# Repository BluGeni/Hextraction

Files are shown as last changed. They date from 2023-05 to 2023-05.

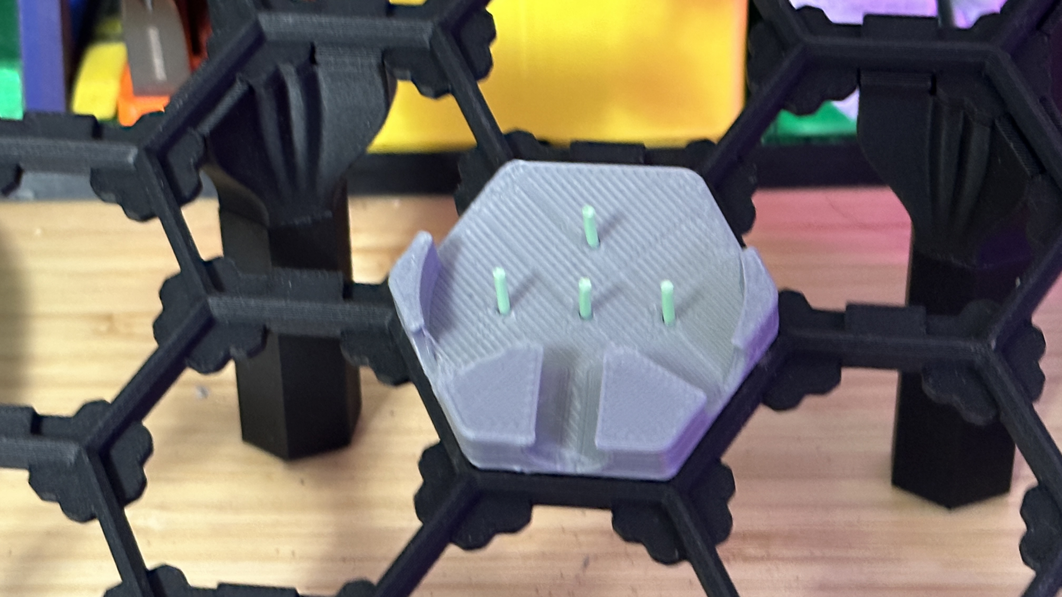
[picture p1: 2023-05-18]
STLs/Tiles/Pachinko/2023-04-21 02.33.19.jpg

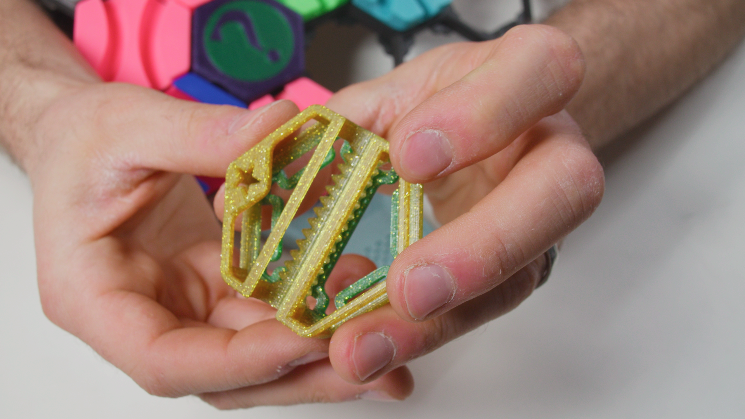
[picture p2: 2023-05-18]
STLs/Tiles/Holographic/holotile (Large).png

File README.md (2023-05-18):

I found it hard to navigate and collect all the tiles on Thangs and wanted to make it easier to see all the tiles and download them at once.

All tiles to print are in the STL folder with READMEs and links to the original are in the named folder.

Mods included:

- a full size board
- 1 piece legs - Basic

Please open a pull request or send me any files or changes you want included.

###### Discord: PapaPinkertinz#7134

# Quick Start:

### Basic Board
1 x 5-15 Plate ([If you need smaller pieces](https://thangs.com/designer/Link%20The%20Cat/3d-model/Hextraction_Board_%5Bfor%20small%20printers%5D-860793))\
1 x 5-7 Plate\
5 x Basic Clips\
2 x Basic On-Ramp\
2 x Universal End Zone\
2 x Basic Back Leg Mount\
2 x Basic Leg Segment 50mm\
2 x Basic Foot Mount Integrated\
2 x Universal Foot Integrated

### Fancy Board:
1 x 5-15 Plate ([If you need smaller pieces](https://thangs.com/designer/Link%20The%20Cat/3d-model/Hextraction_Board_%5Bfor%20small%20printers%5D-860793))\
1 x 5-7 Plate\
17 x Gutter Segment\
3 x Gutter Endcap\
2 x Gutter On-Ramp\
2 x Gutter Leg Mount\
2 x Gutter Leg Start\
2 x Gutter Foot Mount Integrated\
2 x Universal Foot Integrated\
2 x Gutter Leg Segment 50mm

### 14x Basic Tiles:

2x Asterisk Tile\
2x Peace Tile\
2x DIC Tile\
4x DC Tile\
4x X Tile

### 8x Trap Tiles:

4x Double Trap Tiles\
4x Triple Trap Tiles

### 6x Flip-Flop Tiles
These require M3 screws and washers. If these parts are unavailable, substitute 4x Pachinko Tiles and 2x King Tiles.

### 8x Secret Tiles:

2x Secret Flip Flops\
2x Secret DC\
2x Secret X\
2x Secret Lil DC\
8x Secret Lids

### 2x Teleporter Tiles:

2x In Tiles\
2x Out Tiles\
1x In Tile Card\
1x Out Tile Card

### 2x Clone Tiles:

2x Clone Tiles\
1x Clone Tile Card

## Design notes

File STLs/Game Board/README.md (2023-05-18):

These are the official game boards for Hextraction, the hackable, 3D-printable board game. I've created two versions - the Basic model uses minimal filament and prints fast. The "Fancy" Gutter version has many useful features, like ball-catching gutters and detachable feet, but consumes considerably more filament and time.

Basic Board
1 x 5-15 Plate
1 x 5-7 Plate
5 x Basic Clips
2 x Basic On-Ramp
2 x Universal End Zone
2 x Basic Back Leg Mount
2 x Basic Leg Segment 50mm
2 x Basic Foot Mount Integrated
2 x Universal Foot Integrated

Fancy Board:
1 x 5-15 Plate
1 x 5-7 Plate
17 x Gutter Segment
3 x Gutter Endcap
2 x Gutter On-Ramp
2 x Gutter Leg Mount
2 x Gutter Leg Start
2 x Gutter Foot Mount Integrated
2 x Universal Foot Integrated
2 x Gutter Leg Segment 50mm

For assembly instructions for a basic board, watch the Hextraction launch video!

I've designed this to be as modular as possible, so you can create boards of any shape and size. If you're sizing a leg for a given slot, you want it to be 25mm taller for every additional slot between it and the end zone.

Fusion 360 source: https://a360.co/3H6op2f

Hextraction is a 3D-printable, modder-friendly board game designed by me, Zack Freedman of Voidstar Lab. In addition to tiles, you'll also need 10mm steel balls or 3/8" slingshot ammo and a game board. To learn the rules and how to get started, watch the Hextraction video!

Hextraction is absolutely free - it's free of charge - all of my models are here on Thangs, commercial use allowed. It's free-form - you can play with any number of opponents, even zero. It's free to modify - you can create your own tiles and configure your own board.

For more information, visit https://playhextraction.com.

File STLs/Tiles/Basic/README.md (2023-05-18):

These tiles might be nothing but tracks, but they're the bread and butter of the entire game. Along with the board, these are the foundation of Hextraction, the hackable, 3D-printable board game.

These basic tiles are the core of the game - they build more momentum than fancy mechanisms, and they make the game move faster than complex effects. I recommend putting at least one basic tile into the pool per non-basic tile.

The tiles are named for the tracks' appearance - they're not abbreviations, so don't read too far into them!

I also included a blank tile - PLEASE don't print this! It's a base for your own designs, if you'd prefer not to start in Fusion 360.

Fusion 360 source: https://a360.co/42u6wDc
The S and Z tiles were a late addition, so they have a separate source file: https://a360.co/3VYpz6d

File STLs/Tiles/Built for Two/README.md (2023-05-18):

Stretch your turn to the limit with this eye-popping mechanical tile that unfolds to hustle your ball to the end zone. Make foes flip their lids with this wacky tile for Hextraction, the hackable, 3D-printable board game.

The Tile Built for Two is probably the wildest tile I've ever made - it unfolds like a locket to occupy two slots. Or not - the tile still works when it's folded, so you can drop the whole shebang if you're not interested in living large.

Just remember the rules; you have to play the tile and THEN unfold it, so if the adjacent spot is occupied, you can't whip it out. You can only manipulate mechanisms as you play the tile, and immediately afterward, so if that slot opens up, you're stuck. Still, if you have a way to return this to your hand, maybe you can do some surprise plays?

To keep the profile slim, this tile has lower walls than average. Be careful entering at an angle - you might go right over the top.

Print one top, one bottom, and two links. Use M2x8 screws to connect it up. It'll be a very loose fit - this is important to make it fit all kinds of boards. I recommend gluing a few 6x2mm magnets in the holes to hold it shut.

Fusion 360 source: https://a360.co/3psg0Ab

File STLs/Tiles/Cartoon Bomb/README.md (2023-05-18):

Turn your opponents' plans into a smoldering crater with this bulbous banger. It might be the most excessive explosive in Hextraction, the hackable, 3D-printable board game.

The Enormous Cartoon Bomb is pretty much what it says on the tin - it's a big, fat cannonball bomb ripped straight out of Looney Tunes and plopped right onto your game board. The effect triggers when the three-ball rule destroys the tile, causing it to take all of its neighbors down with it. For best results, line up a few copies in a combustible conga line to set up a devastating chain reaction.

This tile isn't just silly - it's genuinely useful in multiplayer games, where conflicting plays constantly clog up the board. It'll create just enough breathing room to get a new tile in play, while significantly delaying the Overdrive endgame. Don't forget that rules card!

Fusion 360 source: https://a360.co/41xxU1R

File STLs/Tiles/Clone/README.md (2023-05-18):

Any fan of pro cycling or late-30's European history will tell you: Two balls are better than one. Double your fun with this special tile for Hextraction, the hackable, 3D printable board game.

When a ball passes through the jagged trigger area, roll another ball down the ramp. It's simple but surprisingly powerful, and part of my recommended "starter kit."

Print one or more tiles and snap off the built-in supports, and don't forget to print the rules card!

Fusion 360 source: https://a360.co/44Vb5Im

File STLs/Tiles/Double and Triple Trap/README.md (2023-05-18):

Craft sneaky strategies with these tricky tiles! They trap the first ball to enter each path, allowing you to outmaneuver foes in Hextraction, the hackable, 3D-printable board game.

The Triple Trap Tile can trap up to two balls, one each in different directions. Be careful entering too fast... it can be a bit touchy.

The Double Trap Tile only captures a single ball, but can be installed in four different orientations. It will occasionally trap too many balls, which are easy to knock loose!

Double Trap source: https://a360.co/3H2dJBS
Triple Trap source: https://a360.co/3MoaVC5

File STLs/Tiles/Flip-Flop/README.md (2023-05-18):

This simple mechanism alternates between sending balls left and right. It's one of the most important tiles in Hextraction, the hackable, 3D-printable board game.

Print one Tile and one Flipper, ideally in PETG or nylon. Insert an M3x8 or M3x10 screw in the flipper, drop an M3 washer onto the tile, align the peg on the flipper with the slot on the tile, and screw it down. Make sure the flipper spins loosely and freely - it might need a touch of grease.

I also snuck in an Advanced version with more entrances. It's more versatile, but also more complex. I recommend printing the basic version first, then upgrading to the Advanced version later.

Fusion 360 source: https://a360.co/3o6D86W

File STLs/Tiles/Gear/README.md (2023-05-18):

Make your foes' heads spin with this revolutionary tile for Hextraction, the hackable, 3D-printable board game.

The Gear Tile's triggered effect lets you lift up an adjacent tile and turn it one notch in either direction. Remember, a notch isn't 60 degrees, it's as far as necessary to make it sit flat. Just be careful if it's got balls on it; if they fall off the tile, you're the one who rolled them! Pull off ten-dimensional gigabrain plays like toggling paths, reversing mechanisms, resetting Trap Tiles, flipping Launchers, and more.

The tile itself can also create some neat strategies - that big peg in the middle can make it behave like a Pachinko, Peace, or DIC Tile.

Don't forget to print that rules card... and some on-theme steampunk copper filament.

Fusion 360 source: https://a360.co/3I9UIxI

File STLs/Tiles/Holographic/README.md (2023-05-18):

Overload the game board in record time with the Holographic Tileframe, a crazy-looking effect tile for Hextraction, the hackable, 3D-printable board game!

It looks like a wireframe, but acts like a time machine - after your ball passes through its skeletonized body, you can play another tile where the path cuts out. Not only does it turbocharge the race to the bottom, it lets you waste opponents' turns by redirecting them off the edge, while giving you twice as many new tiles to throw at them! Don't play this tile recklessly - unless you have a clever trick to jam up your opponent, you might help them more than yourself!

Print the Holo Bottom, the Holo Card, and two each Left Top and Right Top. Glue one set of Tops to the tile, and the other to the rules card.

The crazy aesthetics come at a cost - the Tileframe is the lightest and most fragile tile. Use a tough filament like ABS, and look out for Launchers and straightaways; a high-speed ball can blow it right off the board!

Fusion 360 source: https://a360.co/42NduCU

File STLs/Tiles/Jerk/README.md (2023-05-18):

Sorry, oops, coming through, don't mind me... nothing's more annoying than an overly polite tile shouldering in on your turf. Shove your way to victory - gently - with this tactically awkward utility tile for Hextraction, the hackable, 3D printable board game.

As a rare self-explaining tile, this one has the rule printed right in - when you play it, swap it with an adjacent tile. It also tells you to apologize, though Rule 0 keeps this from affecting the gameplay. Do it if you want, or don't... you jerk.

Not only does it have nothing but a single teeny-tiny turn, it can be placed in "illegal" ball-trapping positions. Y'know, in case shoving your opponents' plans aside isn't obnoxious enough already.

Also, you can technically use this to move a ball up the board if you play it next to some kind of King Tile variant that lets you wait a turn? I don't know, this tile's a jerk.

Fusion 360 source: https://a360.co/3o1hnFS

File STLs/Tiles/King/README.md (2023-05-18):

This tile travels across the game with a ball on board, opening big-brain plays almost as bizarre as en passant. Put your foes in check with this chess-inspired tile for Hextraction, the hackable, 3D-printable board game.

Even though it's got a neat self-resetting mechanism, this tile is fully printed, so if you don't have the hardware to make the Flipper Tile, you can capture some of its gameplay with the King. Since it needs open slots to work, it's strongest in the early and midgame. Consider adding some Bomb Tiles and other tile removers to open up more wiggle room!

I strongly recommend printing the Spring in PLA for stiffness, and the other components in PETG or nylon for smoothness. Print the Knob with the icon facing up, and the Upper with arrows against the plate, supports enabled. The Lower, Spring, and Kard don't need supports. To assemble:

Put a thin bead of glue around the center peg on the King Lower, drop in the Spring flat side down, and let it set.
If possible, apply some plastic-safe grease to the Knob's underside and tabs.
Push the Knob into the Upper, and make sure the Knob's tabs nest into the Upper's tracks.
Apply glue to the four pegs on the Lower. Drop the Knob and Upper onto the Lower and let the glue set.
If necessary, apply more grease to make the motion smooth.
Fusion 360 source: https://a360.co/45aGjeT

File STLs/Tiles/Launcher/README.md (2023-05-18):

Make a strategy that defies gravity with this kinetic tile for Hextraction, the hackable, 3D-printable board game. Warning: It'll put your eye out.

When a ball enters the Launcher Tile, its effect activates - pull back the spring-loaded pusher and release it to fire the ball into the upper-left or upper-right edge. Positioning is important - since almost every tile is designed for balls to enter the TOP edges, very few will work if you start at the wrong end of the ice-cream cone. Prepare by stocking the pool with extra Asterisks, Pachinkos, Gears, "illegal" basics, and other compatible tiles. The Flipper Tile actually DOES work with the Launcher, provided the flipper is pointing in the other direction.

For the strongest launch, brace the tile against the board with one hand, while using the other to launch. The snappier the release, the stronger the launch. PLEASE don't let kids play with this tile - while it shouldn't be powerful enough to injure anyone, accidents do happen. You also don't want your vile offspring firing pencils out of this thing.

The Launcher Tile has a print-in-place mechanism - simply print the tile with supports enabled on the build plate only. Don't use PLA or composites - you need the lowest friction possible. After printing and cleaning up, use a Q-tip or toothpick to apply a plastic-safe grease to the slider track, and use tweezers to install a McMaster 9044K11 extension spring on the pegs below. Depending on your printer's support interface settings, you may need to thin the pegs down with a craft knife to fit the spring.

Also, don't forget to print the rules card - this uses a triggered effect to fire the ball!

Fusion 360 source: https://a360.co/3LWqEXA

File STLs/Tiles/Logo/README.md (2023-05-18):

I designed these tiles for the release video of Hextraction, the hackable, 3D-printable board game. They're meant to be decorative, but if you're adventurous, you could play them! My goal was a cool-looking title card shot and thumbnail, not fun gameplay, so they have downright bizarre track arrangements that don't work in many orientations. If you're an experienced player, these could spice up your pool without bogging you down with rules and mechanisms. If you're new, I recommend printing another tile instead.

Print the A parts face-down on the plate, and the B parts face-up. Enable ironing on all top surfaces. Print the Overlays in a contrasting color. Glue each tile's A and B parts together, then glue the Overlay on top.

While these have notches in all six positions, they were intended to be installed with the text pointing towards the bottom-right. Other orientations will make many of the paths unusable. Also, be gentle - these tiles weren't intended to be shuffled, so they're particularly fragile.

If you'd like to improve these, I recommend closing some of the notches to restrict the orientations, and maybe rearranging some of the tracks. I was also thinking of adding a rule: "The 'TRAC' tile overwrites the 'HEX' tile's neighbors, and the 'TION' tile overwrites the 'TRAC' tile's neighbors." Or maybe "When a roll ends, if the 'HEX,' 'TRAC,' and 'TION' tiles were touched exactly once, in that order, rearrange any number of tiles and roll again."

Fusion 360 source: https://a360.co/42ywXYu

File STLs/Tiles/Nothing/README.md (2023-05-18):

When nothing remains, everything is equally possible. Dump your hand with this simple utility tile for Hextraction, the hackable, 3D printable board game.

I developed this as an example of a self-explaining tile - you don't need a rules card if the rule is on the tile itself! Discarding your hand is a big deal in Magic, but in Hextraction, it just means you get to cycle in a new one at the end of your turn. The tile's bare-bones path means you'll always have a place to play it. Between us nerds, this one also lets you set up some "illegal" plays that connect the top edge to a top-side edge. Make sure the ball has some momentum!

Fusion 360 source: https://a360.co/42NcFKk

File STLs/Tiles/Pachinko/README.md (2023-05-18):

Let chaos reign with this unpredictable tile! Who knows where the ball will end up?

After printing, wedge some small pieces of filament into the holes to make the pegs. If the holes come out too small, touch up with a 2mm drill. You can also use M2 screws.

Fusion 360 source: https://a360.co/459EwXo

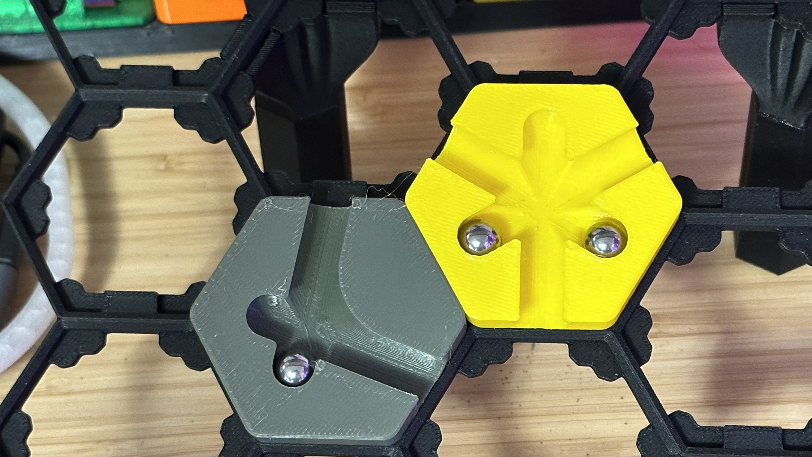
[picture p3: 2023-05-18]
STLs/Tiles/Double and Triple Trap/2023-04-21 02.33.58.jpg

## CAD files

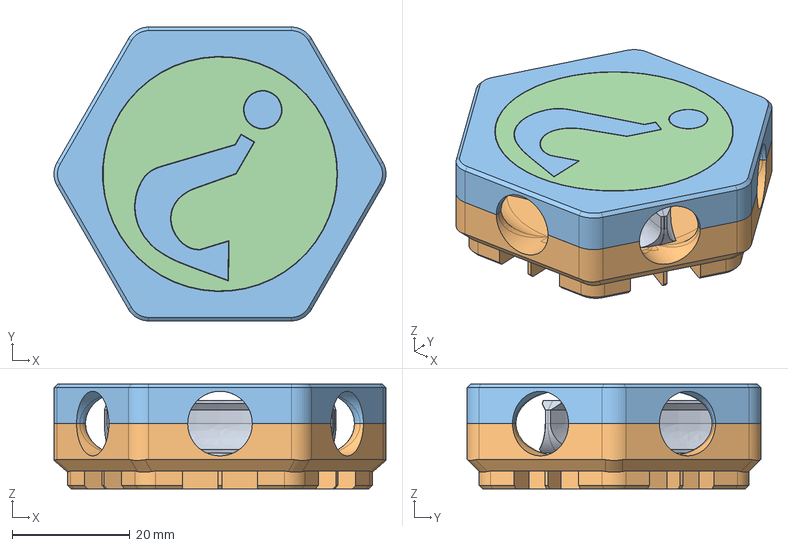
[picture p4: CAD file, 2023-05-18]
STLs/Tiles/SecretMystery/Secret Flipper Example Assembly - Dont Print.step
56.5 x 50.0 x 17.8 mm
Flippy Dingus
Tile (1)

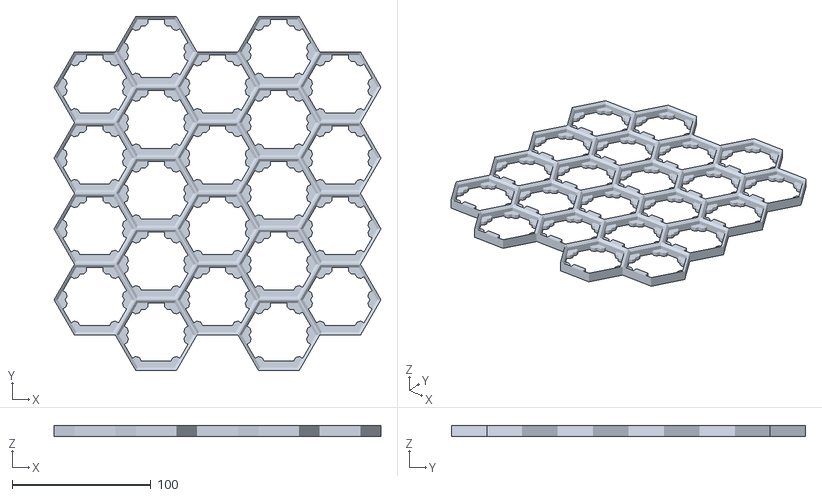
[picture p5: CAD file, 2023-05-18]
STLs/Game Board/Full Board.stl
235.3 x 254.8 x 7.75

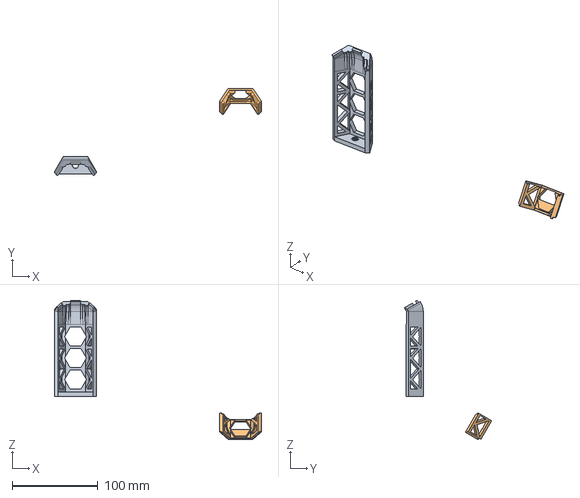
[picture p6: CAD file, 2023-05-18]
CAD/Combined Leg Basic.step
240.9 x 101.7 x 162.3 mm

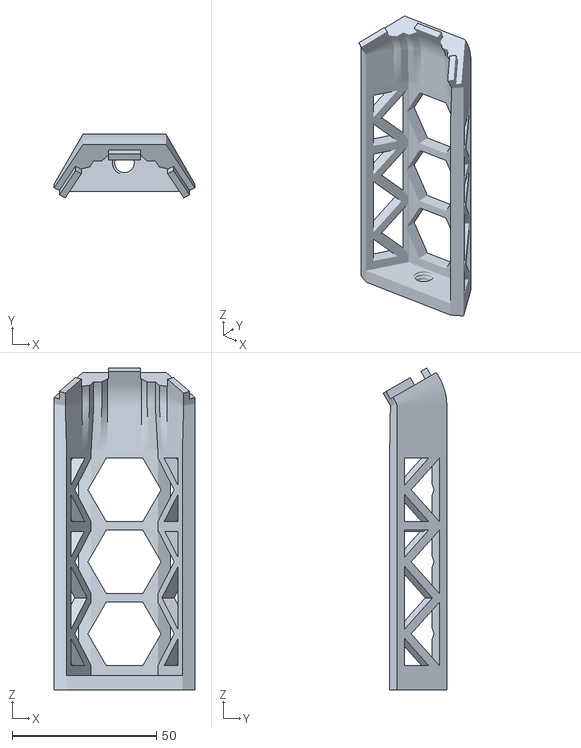
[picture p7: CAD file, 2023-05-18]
STLs/Game Board/Combined Basic Leg.stl
48.9 x 22.1 x 111.8

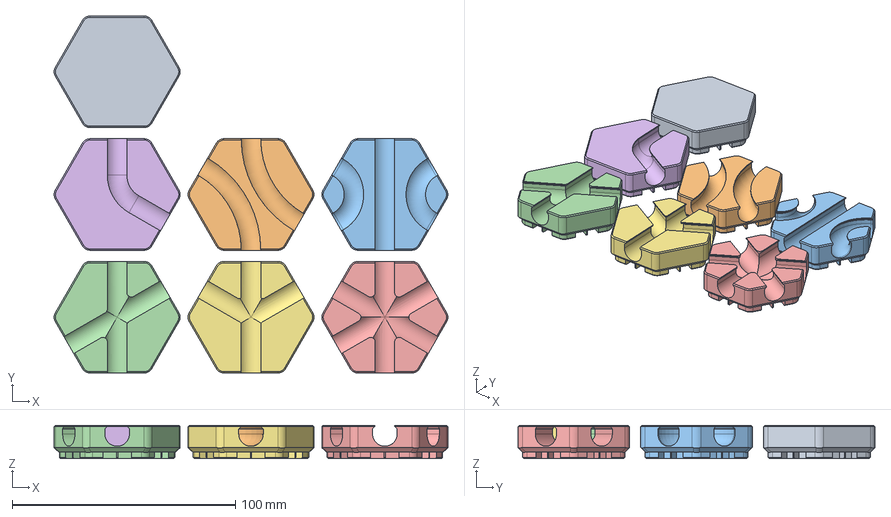
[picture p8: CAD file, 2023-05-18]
STLs/Tiles/aTemplate/All Basic Tiles.step
176.5 x 160.0 x 15.0 mm

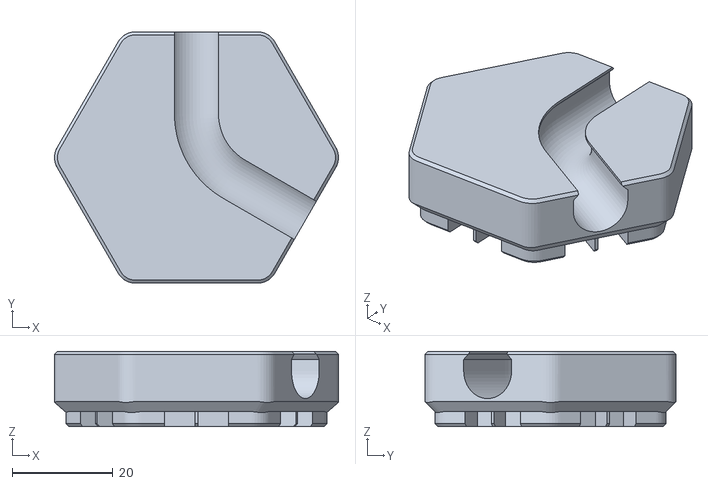
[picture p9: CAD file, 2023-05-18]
STLs/Tiles/Basic/J Tile.stl
56.5 x 50.0 x 15.0

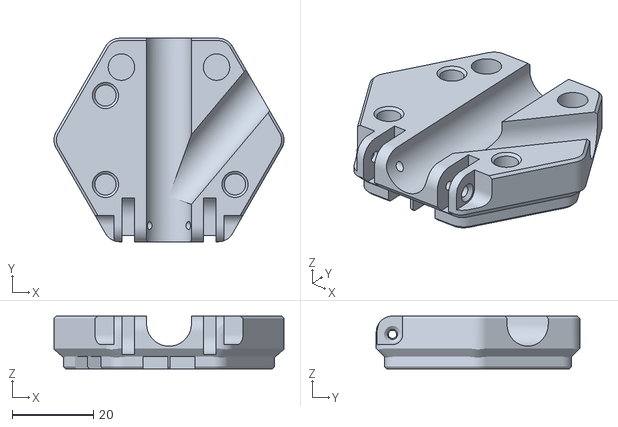
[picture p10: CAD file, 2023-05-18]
STLs/Tiles/Built for Two/Double Tile Bottom.stl
56.5 x 50.0 x 13.0

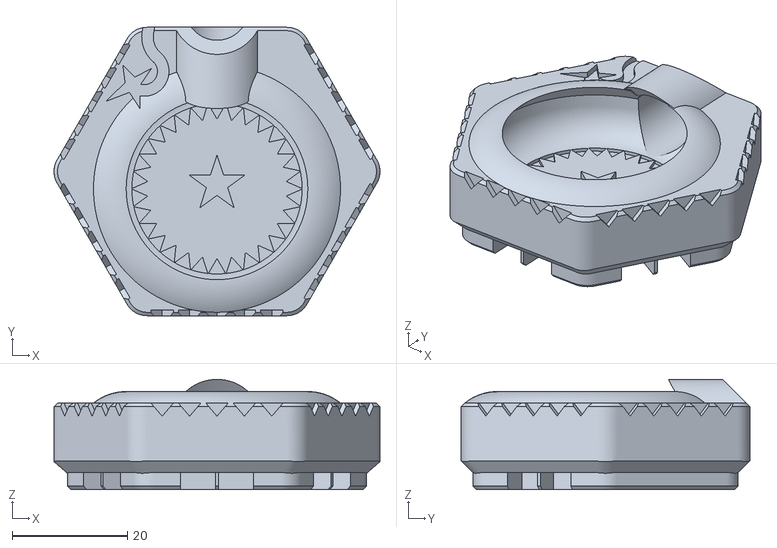
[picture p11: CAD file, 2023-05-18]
STLs/Tiles/Cartoon Bomb/Bomb Tile.stl
56.5 x 50.0 x 19.1

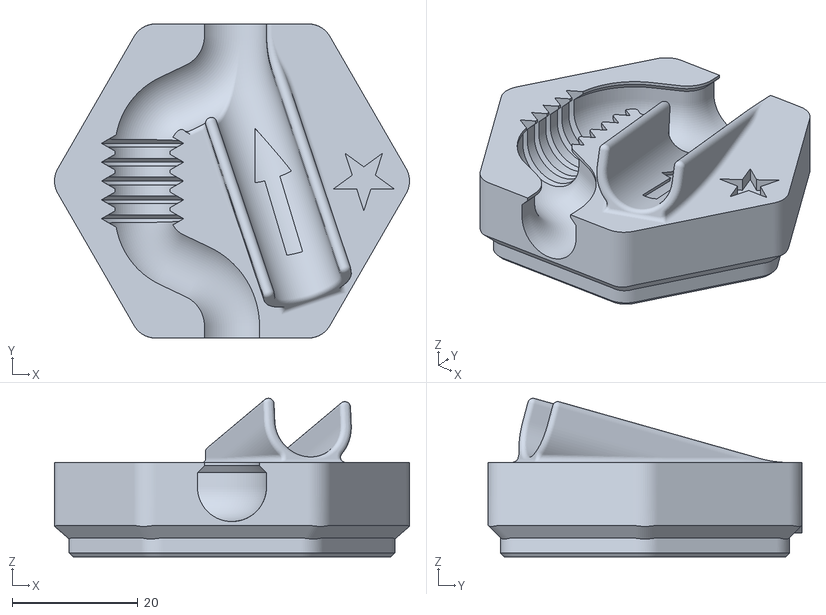
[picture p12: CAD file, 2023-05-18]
STLs/Tiles/Clone/Clone Tile.stl
56.5 x 50.0 x 25.2

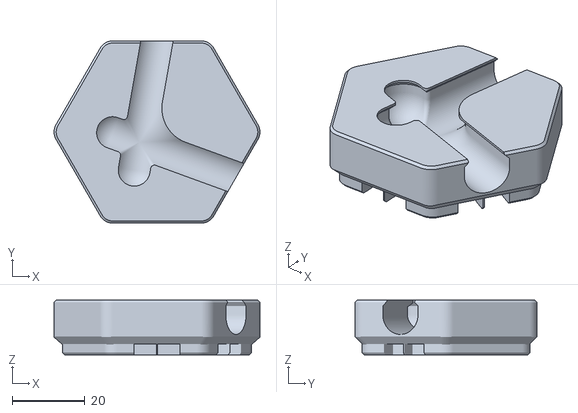
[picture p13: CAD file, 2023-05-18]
STLs/Tiles/Double and Triple Trap/Double Trap Tile.stl
56.5 x 50.0 x 15.0

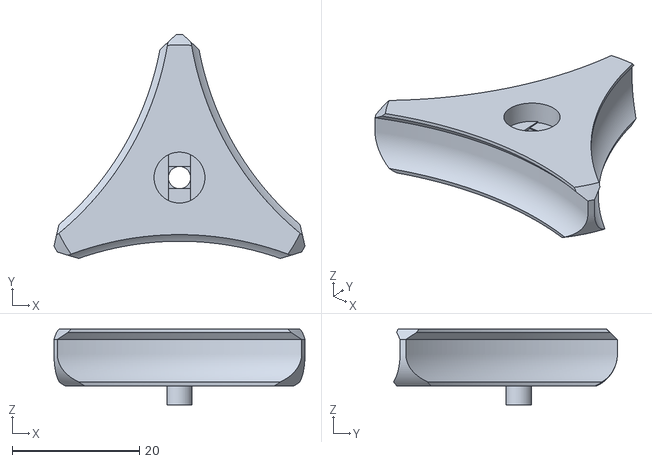
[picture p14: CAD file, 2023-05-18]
STLs/Tiles/Flip-Flop/Flip Flop Tile Flipper.stl
39.5 x 35.2 x 11.9

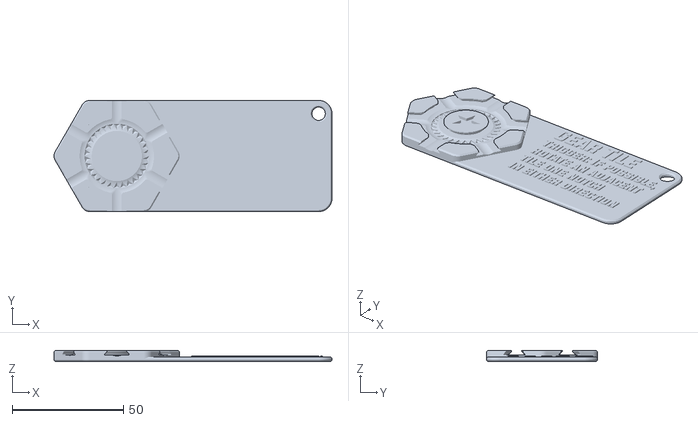
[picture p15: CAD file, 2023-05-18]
STLs/Tiles/Gear/Gear Card.stl
125.0 x 50.0 x 5.00

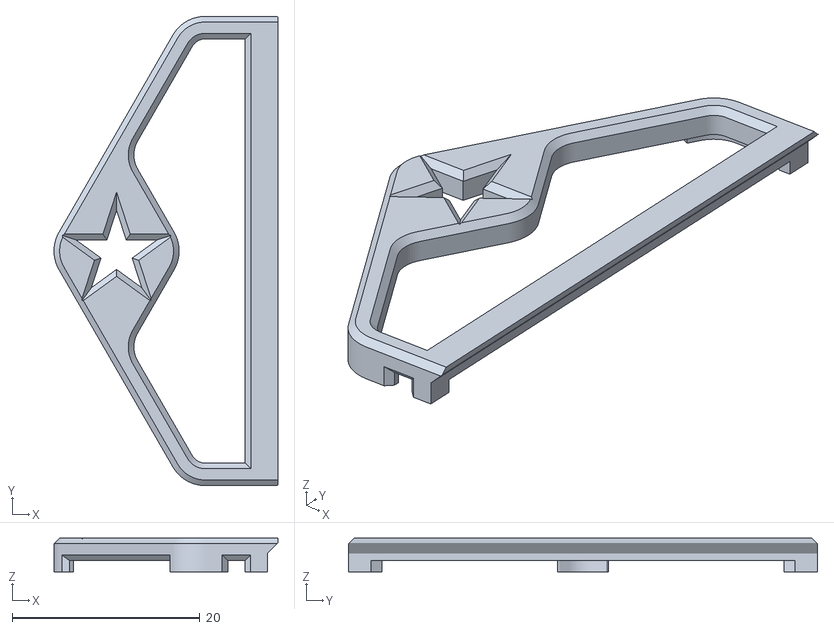
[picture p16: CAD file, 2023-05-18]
STLs/Tiles/Holographic/Holo Left Top.stl
23.9 x 50.0 x 3.60

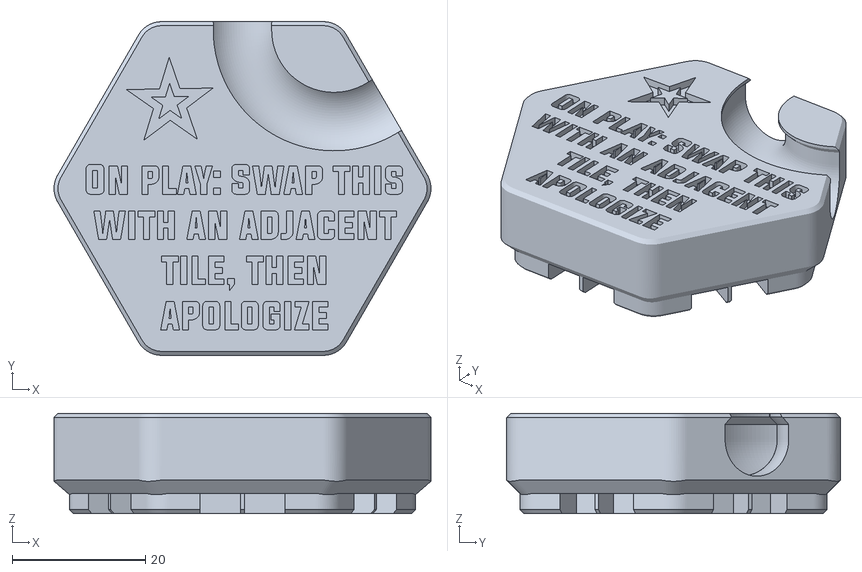
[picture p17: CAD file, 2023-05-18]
STLs/Tiles/Jerk/Jerk Tile (1).stl
56.5 x 50.0 x 15.0

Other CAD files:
STLs/Tiles/King/King Spring.stl
STLs/Tiles/Launcher/Launcher Tile Card.stl
STLs/Tiles/Logo/Brand Tile 3A.stl
STLs/Tiles/Nothing/Tile with Nothing.stl
CAD/Baseplate v2.step
STLs/Game Board/5-15 Plate.stl
STLs/Game Board/5-7 Plate.stl
STLs/Game Board/Basic Back Leg Mount.stl
STLs/Game Board/Basic Clip.stl
STLs/Game Board/Basic Foot Mount Heat Set.stl
STLs/Game Board/Basic Foot Mount Integrated.stl
STLs/Game Board/Basic Front Leg Mount.stl
STLs/Game Board/Basic Leg Segment 12mm.stl
STLs/Game Board/Basic Leg Segment 50mm.stl
STLs/Game Board/Basic Leg Segment.stl
STLs/Game Board/Basic On-Ramp.stl
STLs/Game Board/Combined Basic Leg heatset.stl
STLs/Game Board/Gutter Endcap.stl
STLs/Game Board/Gutter Foot Mount Heat Set.stl
STLs/Game Board/Gutter Foot Mount Integrated.stl
STLs/Game Board/Gutter Leg Mount.stl
STLs/Game Board/Gutter Leg Segment 12mm.stl
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

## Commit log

2023-05-18 Adds link to smaller board pieces
2023-05-18 rename folder
    [5-15 Plate.stl, 5-7 Plate.stl, Basic Back Leg Mount.stl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]
2023-05-18 adds combined legs for basic
    [Combined Basic Leg heatset.stl, Combined Basic Leg.stl, Combined Leg Basic.step]
